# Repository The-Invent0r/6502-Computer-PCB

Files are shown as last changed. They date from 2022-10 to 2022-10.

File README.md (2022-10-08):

# 6502-Computer-PCB

DISCLAIMER: I DELETED ALL OF THE CONNECTIONS FOR GRANT SEARLE'S VIDEO+KEYBOARD INTERFACE BEFORE UPLOADING THE FILES. IF YOU WANT TO ADD IN THE VIDEO+KEYBOARD INTERFACE PLEASE TAKE A LOOK AT HIS WEBSITE (http://searle.x10host.com/MonitorKeyboard/index.html) AND FOLLOW THE DIRECTIONS ON THERE. IT MIGHT BE WORTH IT TO PROTOTYPE THE INTERFACE ON BREADBOARDS FIRST.

I made this Modified version of Ben Eater's 6502 computer PCB and decided instead of adding a VGA video card, I wanted to connect this to a CRT monitor using a composite video cable. 
I decided to add in a 6551 ACIA (Asyncronous Communications Interface Adapter) to give the computer serial I/O capabilites. I then found Grant Searle's video+keyboard interface and decided to incorporate that into my design. 
The only issue was that my 6551 was sending and receiving data at 19200 baud, and the video+keyboard interface was running at 115200 baud. Luckily it was an easy fix to go into the software and update the USART_BAUD variable from 115200u1 to 19200u1. 
However, before uploading the code I changed the fuse bytes to ensure that the 2 AVR chips were running at the correct crystal oscillator frequencies. 
To upload the code for the keyboard chip I used WinAVR. I found that before uploading the keyboard interface code, I needed to change the file name to main.c and I also had to create my own makefile for the atmega328p. 
For the video chip I decided to use the .hex file, and burn that directly into the other atmega328p using the command line. 
When I first prototyped this circuit on breadboards I had a lot of issues which I later discovered were caused by using a low quality breadboard. So if all off your connections and software are correct, try using a more expensive but higher quality BB830 breadboard.
When you first connect the circuit to an LCD monitor or CRT monitor you should see a cursor blinking. In order to conduct a loopback test of the circuit, simply connect the Rx pin to the Tx pin on the keyboard chip, then connect the PS2 keyboard and start typing. If it works then you'll see the correct characters on the screen.

I also made a YouTube video briefly documenting my progress and demonstrating the workings of the computer. (https://youtu.be/8I7XNCFC5iU)




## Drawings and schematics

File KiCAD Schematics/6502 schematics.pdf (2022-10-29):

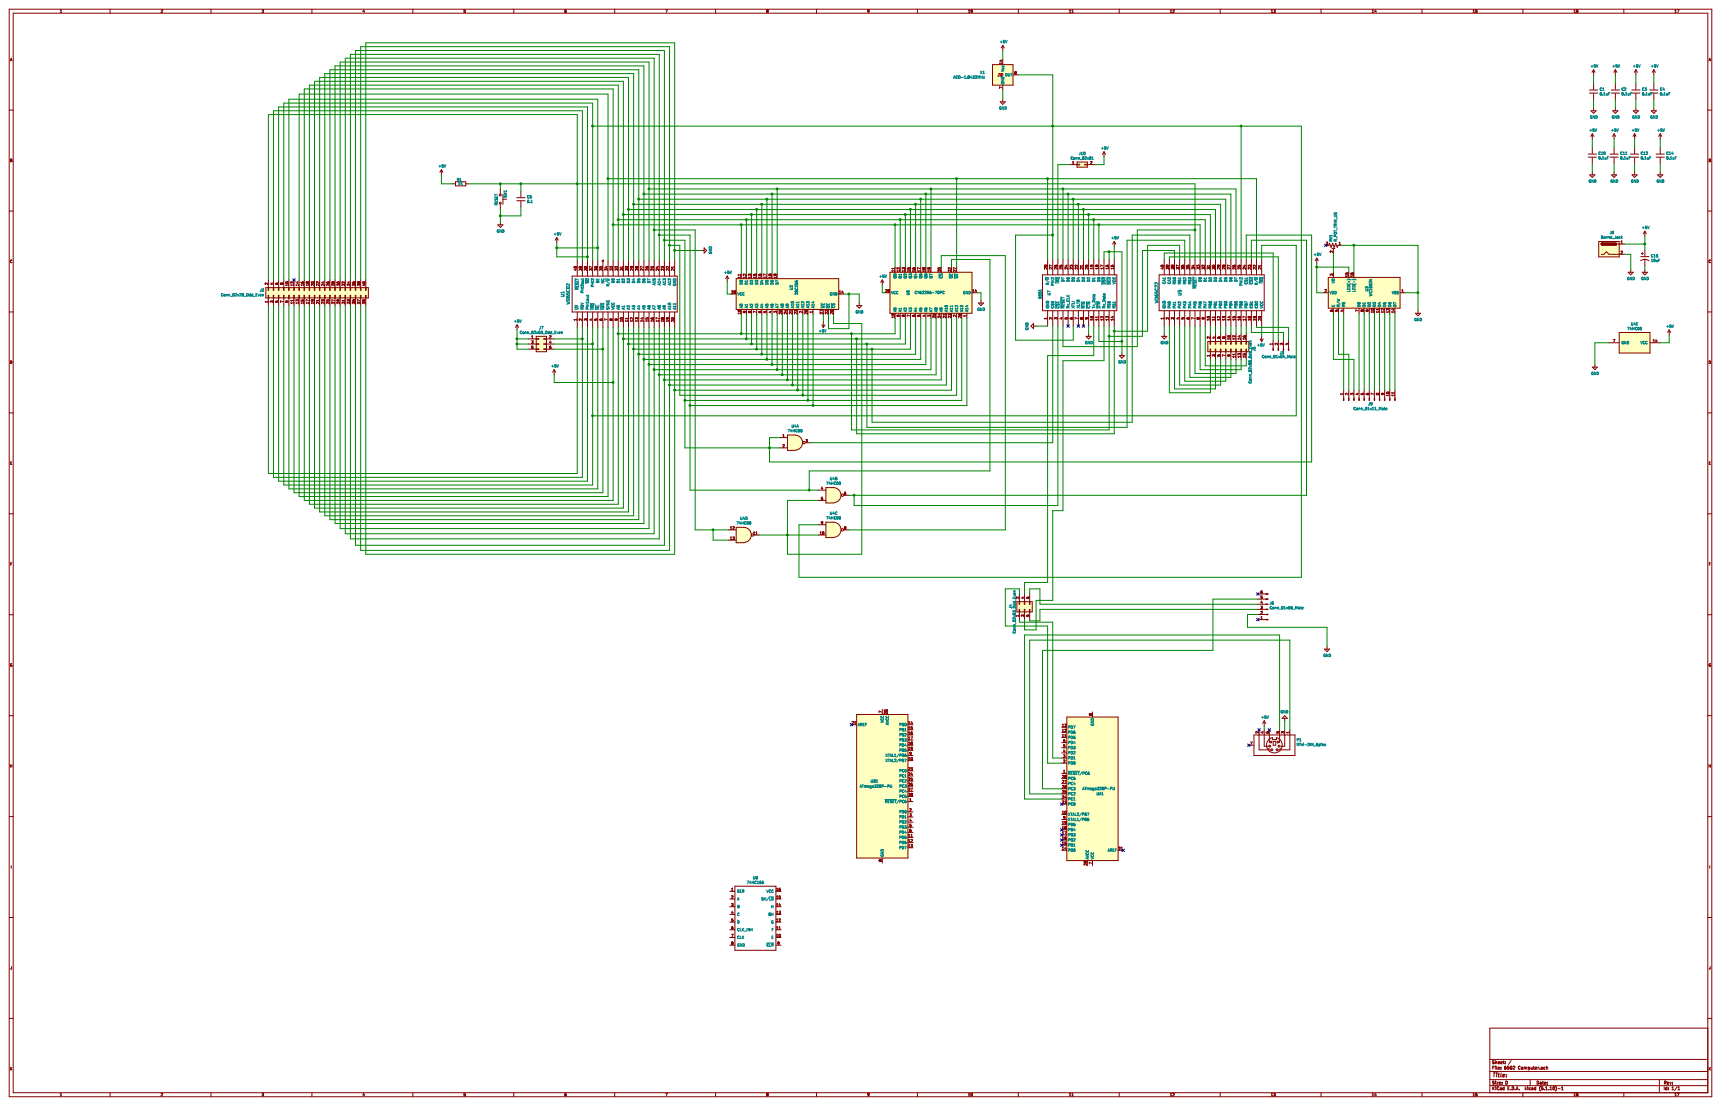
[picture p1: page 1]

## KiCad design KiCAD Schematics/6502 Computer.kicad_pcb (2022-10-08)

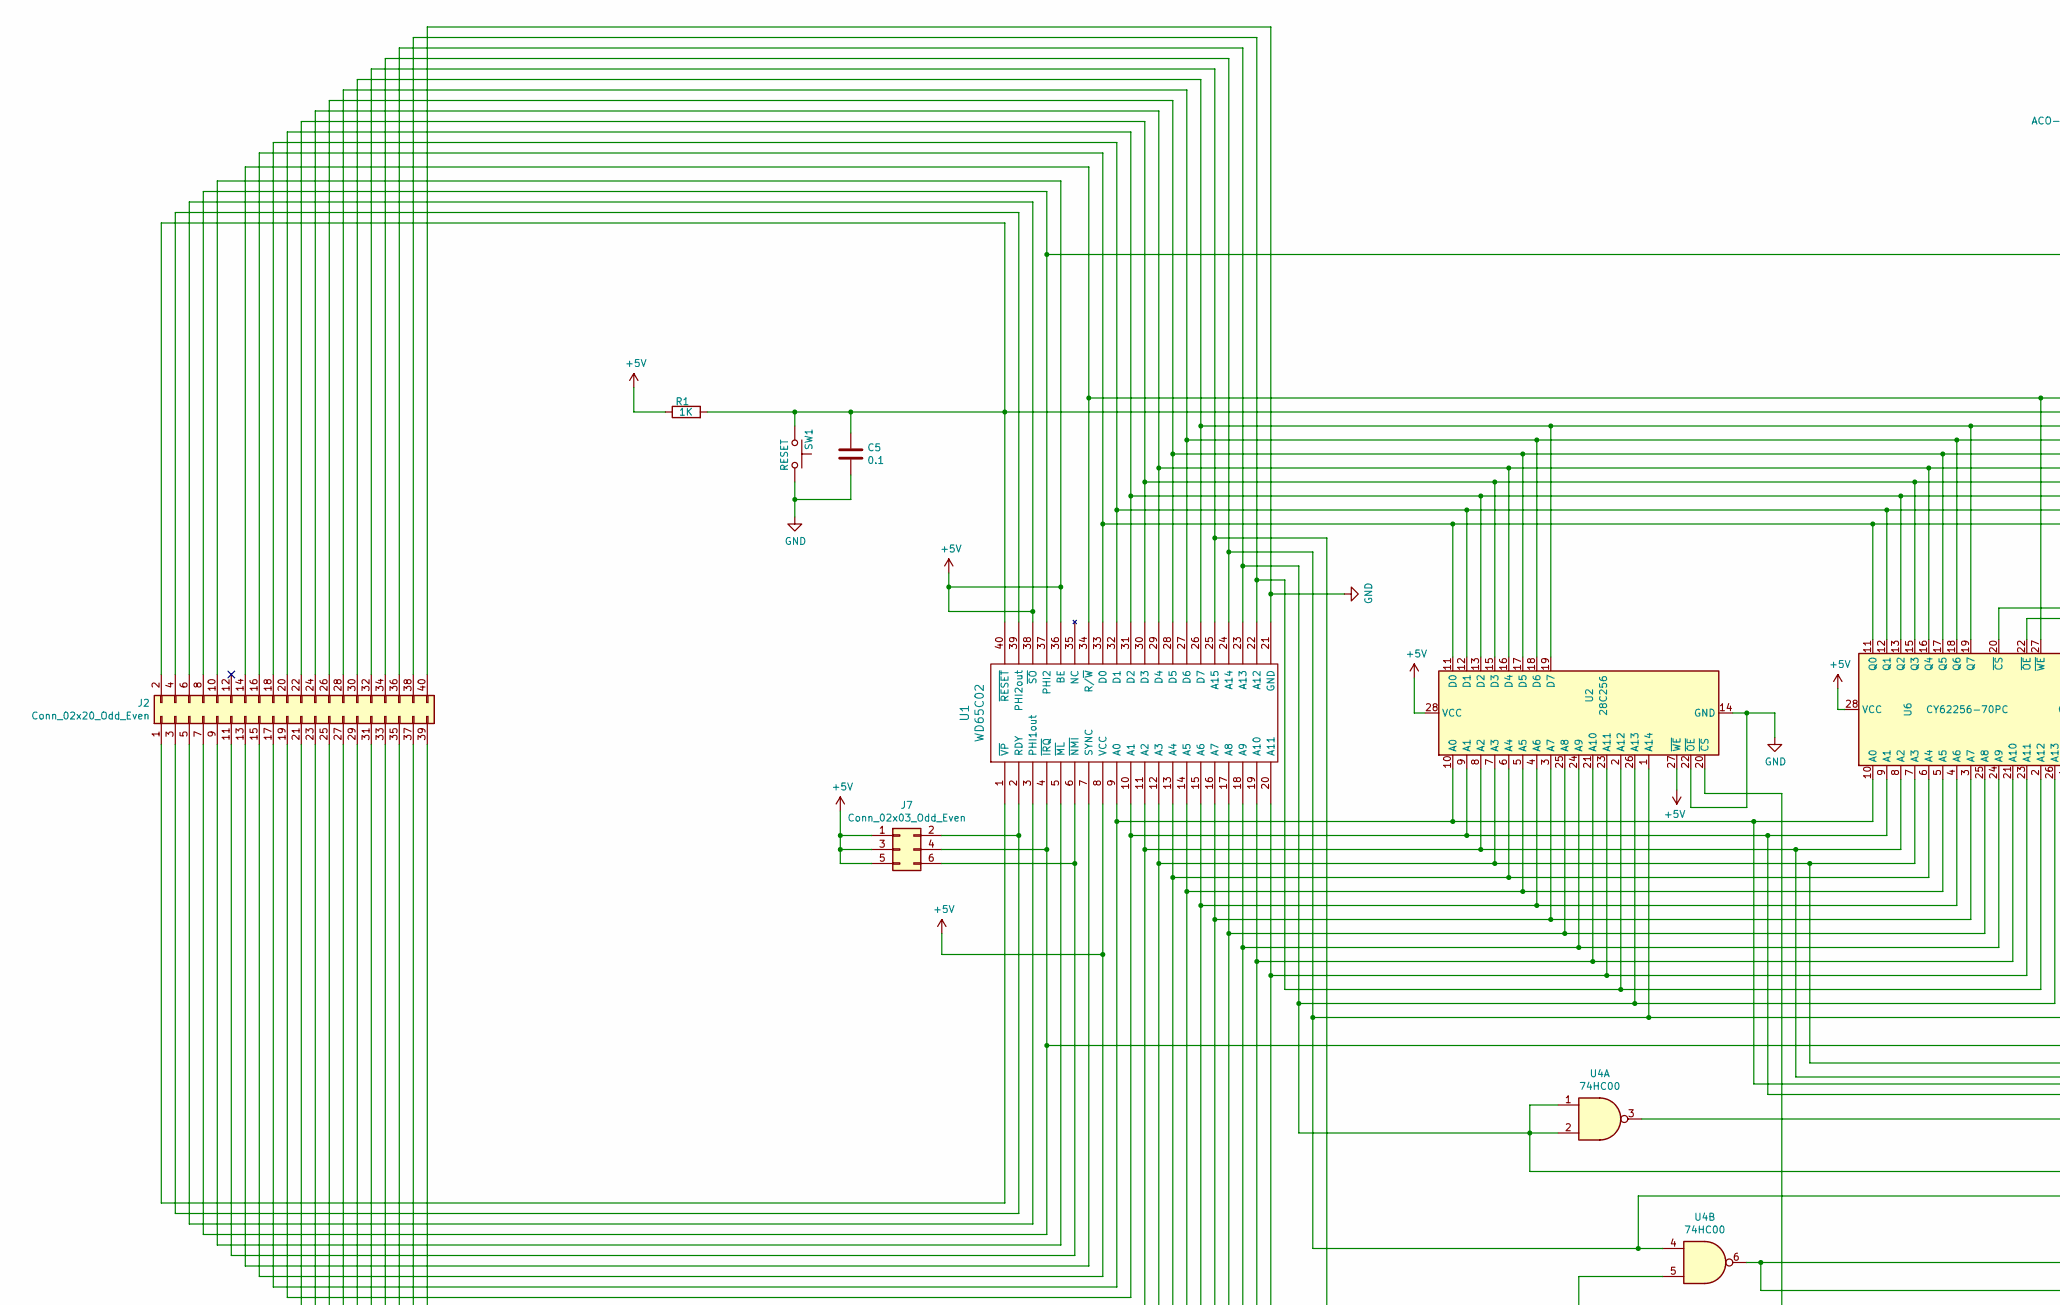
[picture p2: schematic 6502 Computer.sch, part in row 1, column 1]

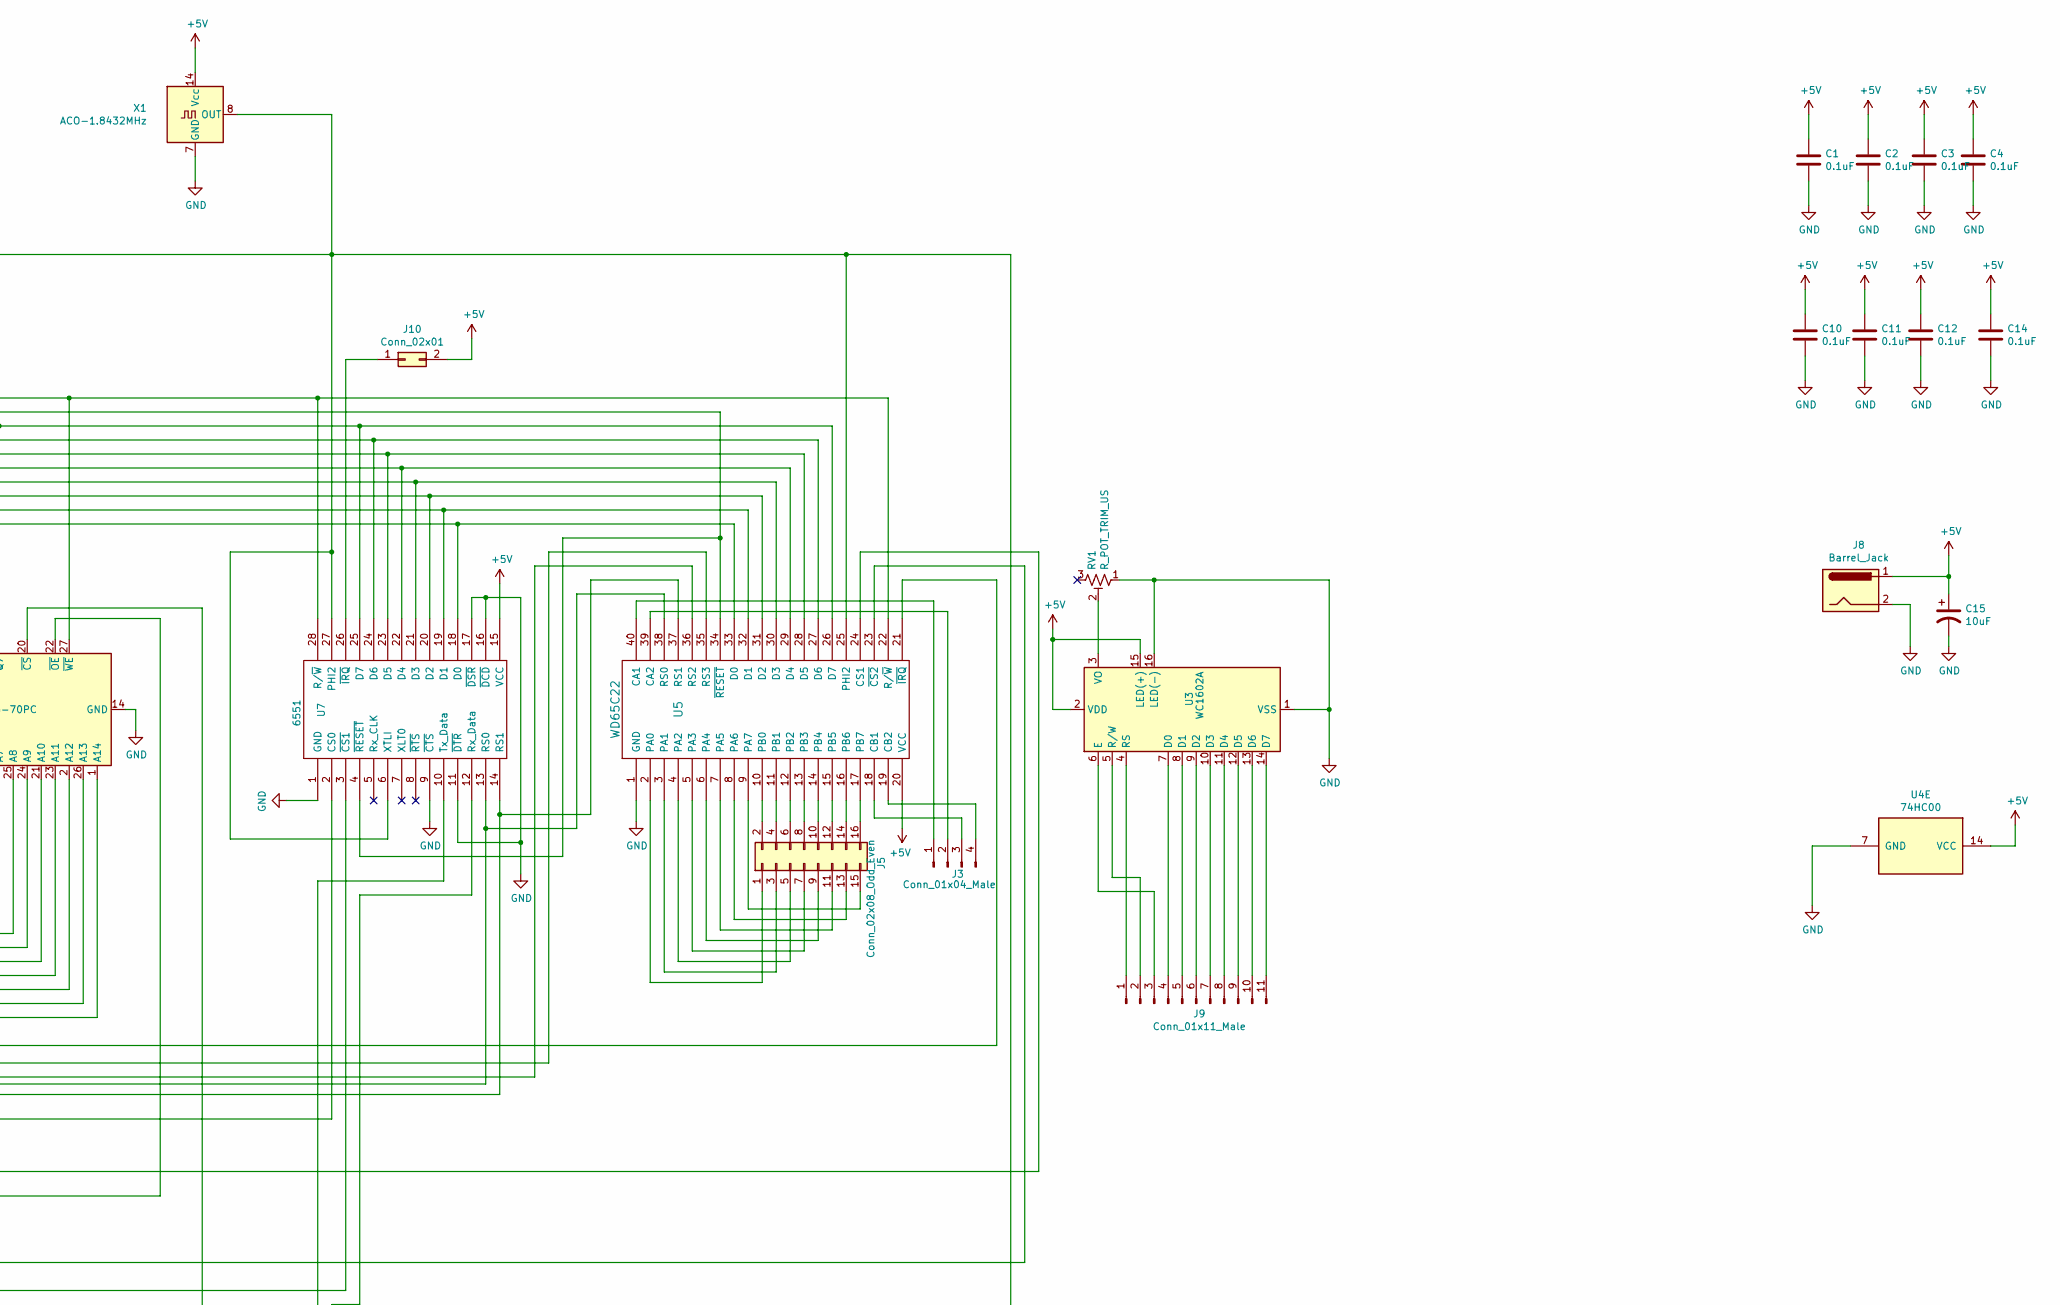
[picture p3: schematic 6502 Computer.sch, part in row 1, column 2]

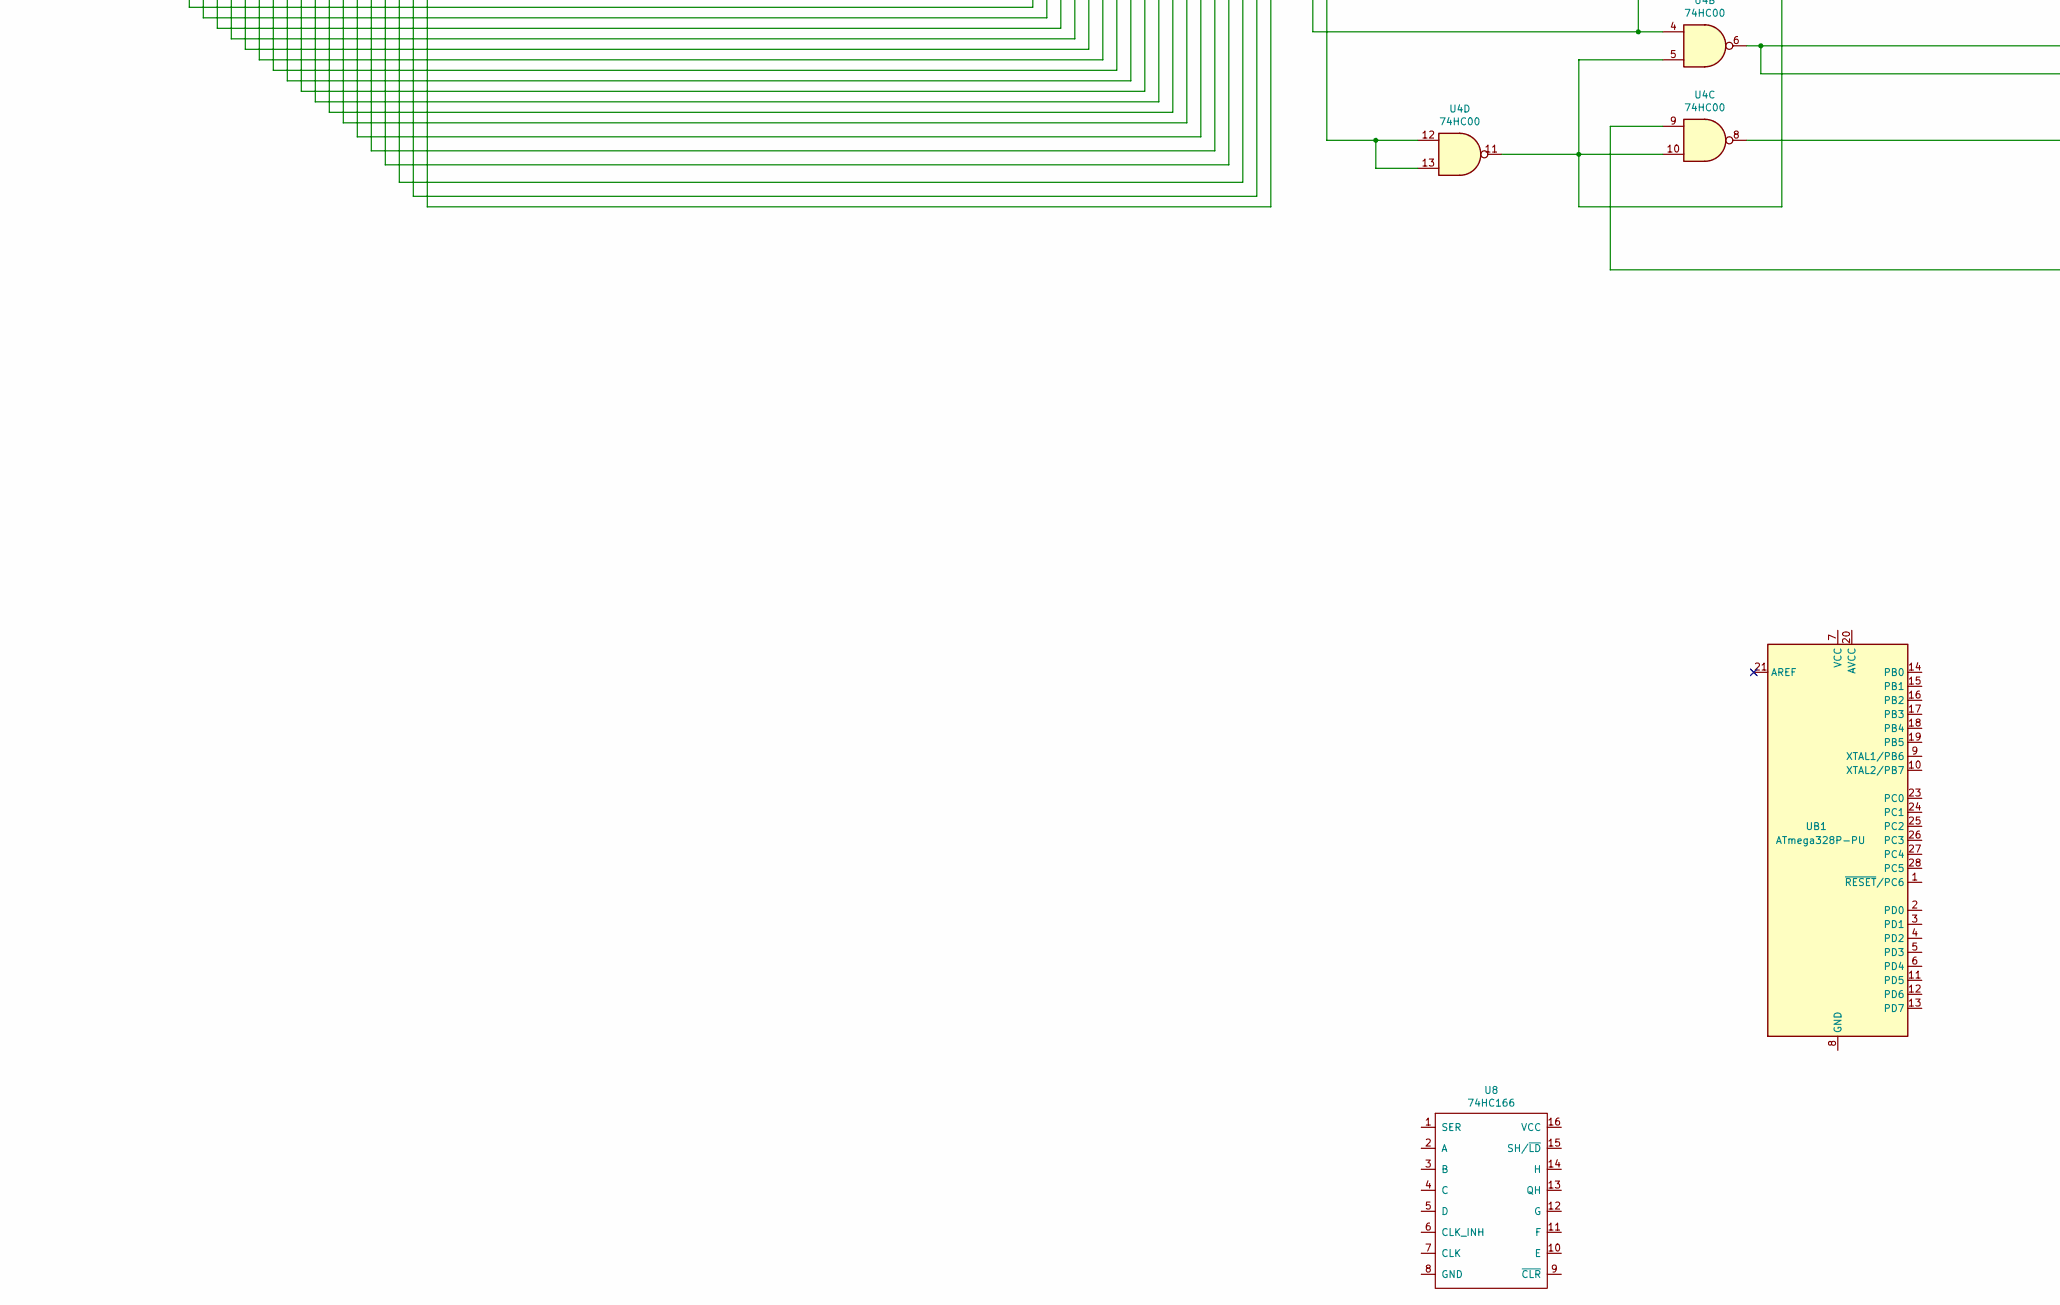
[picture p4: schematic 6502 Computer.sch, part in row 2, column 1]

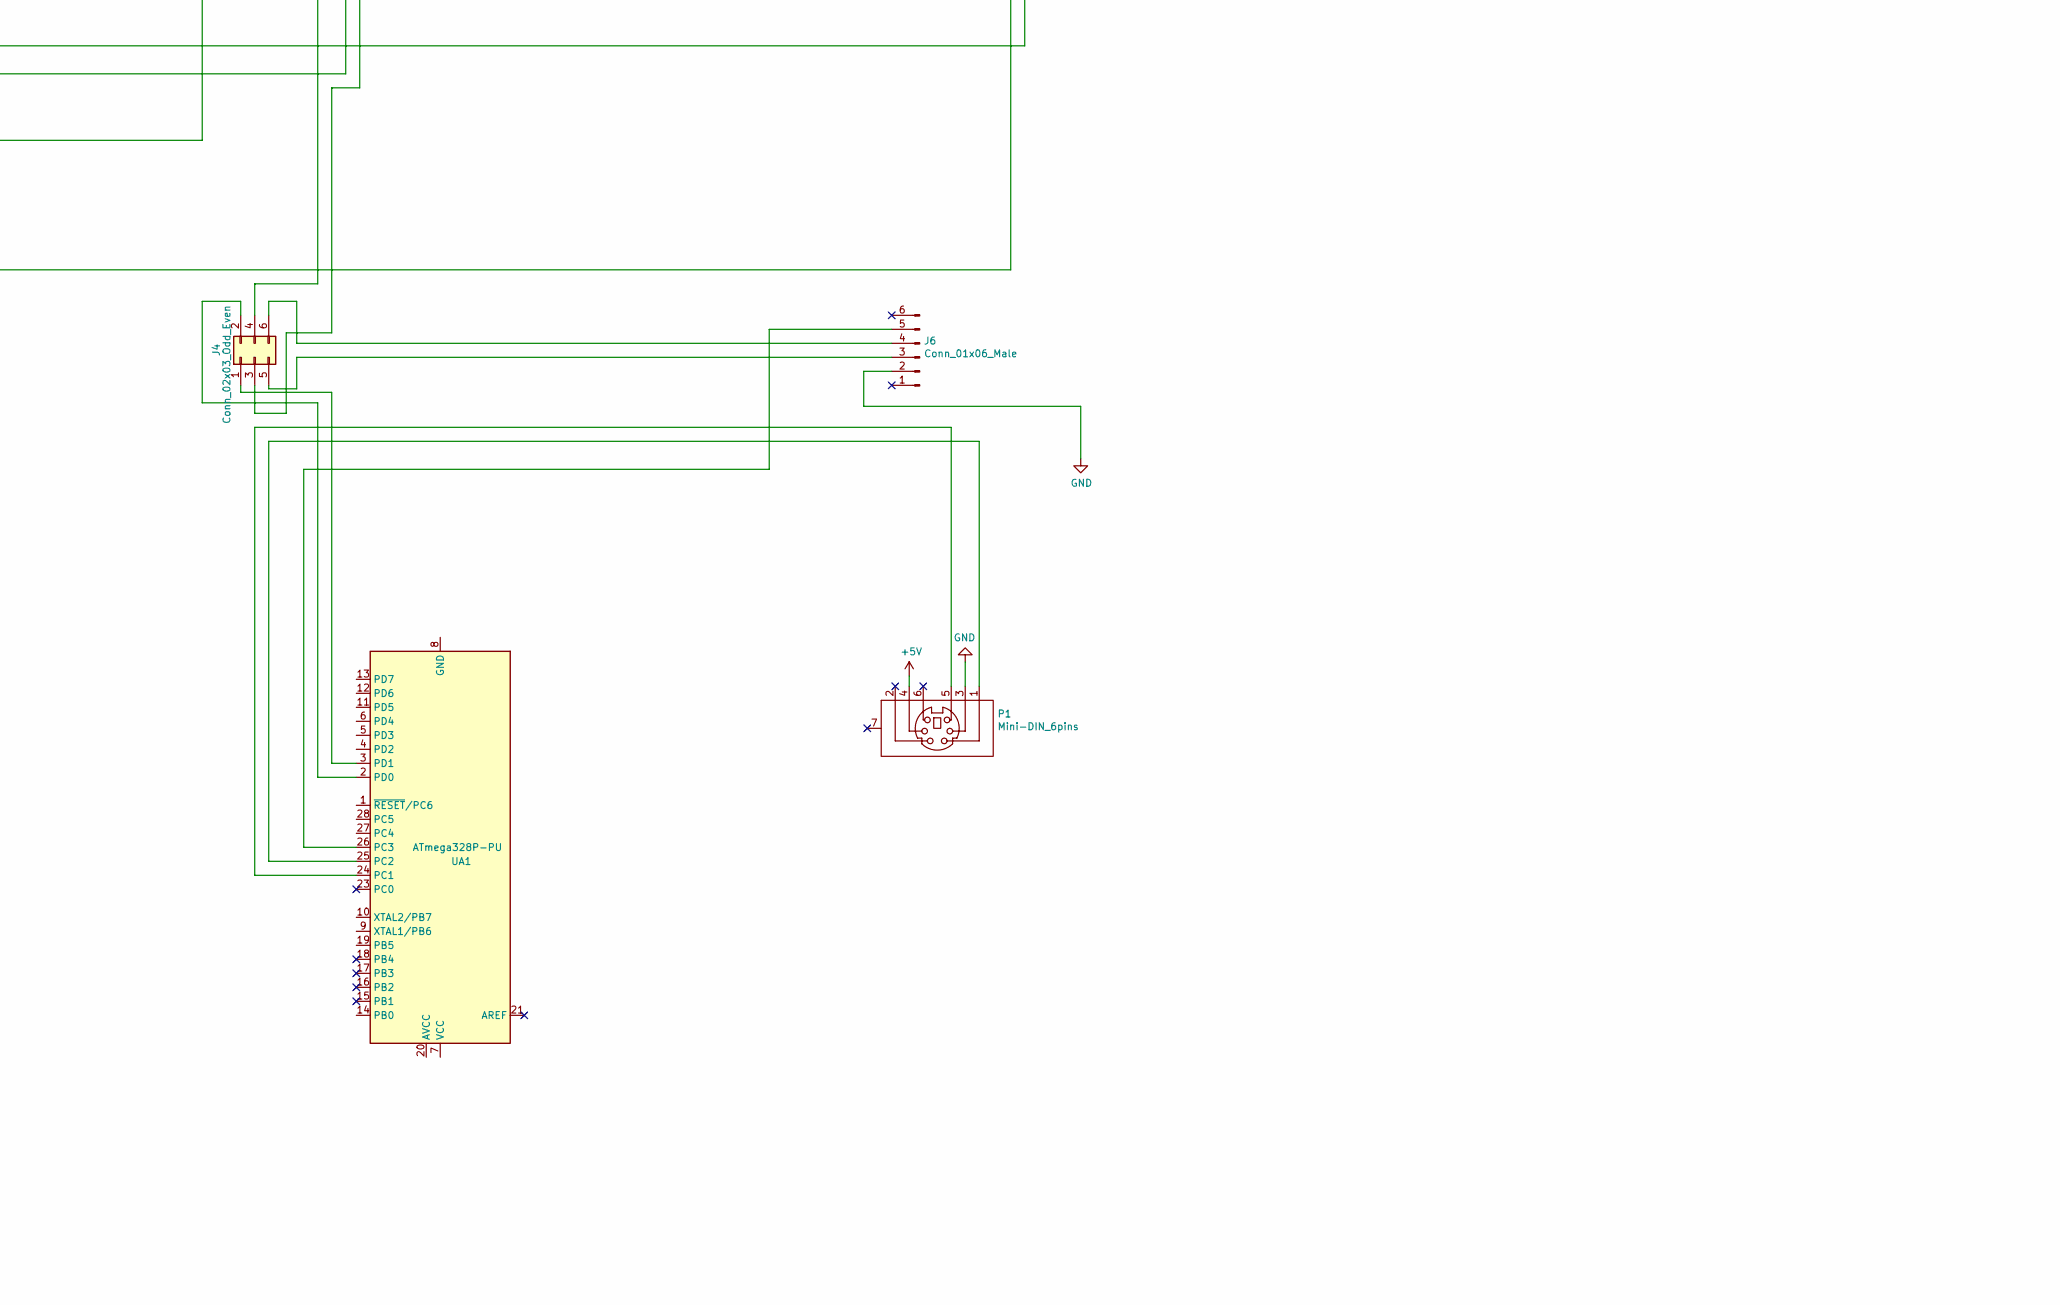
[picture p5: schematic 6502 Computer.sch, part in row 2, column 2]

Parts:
C1, C2, C3, C4, C10, C11, C12, C14: 0.1uF; C_Disc_D4.3mm_W1.9mm_P5.00mm
C5: 0.1; C_Disc_D4.3mm_W1.9mm_P5.00mm
C15: 10uF; CP_Radial_D5.0mm_P2.00mm
J2: Conn_02x20_Odd_Even; PinHeader_2x20_P2.54mm_Vertical
J3: Conn_01x04_Male; PinHeader_1x04_P2.54mm_Vertical
J4, J7: Conn_02x03_Odd_Even; PinHeader_2x03_P2.54mm_Vertical
J5: Conn_02x08_Odd_Even; PinHeader_2x08_P2.54mm_Vertical
J6: Conn_01x06_Male; PinHeader_1x06_P2.54mm_Horizontal
J8: Barrel_Jack; BarrelJack_CUI_PJ-063AH_Horizontal
J9: Conn_01x11_Male; PinHeader_1x11_P2.54mm_Vertical
J10: Conn_02x01; PinHeader_2x01_P2.54mm_Vertical
P1: Mini-DIN_6pins; Connector_Mini-DIN_Female_6Pin_2rows
R1: 1K; R_Axial_DIN0207_L6.3mm_D2.5mm_P7.62mm_Horizontal
RV1: R_POT_TRIM_US; Potentiometer_Bourns_3386C_Horizontal
SW1: RESET; SW_PUSH_6mm_H5mm
U1: WD65C02; DIP-40_W15.24mm_Socket_LongPads
U2: 28C256; DIP-28_W15.24mm_Socket_LongPads
U3: WC1602A
U4: 74HC00; DIP-14_W7.62mm_Socket_LongPads
U5: WD65C22; DIP-40_W15.24mm_Socket_LongPads
U6: CY62256-70PC; DIP-28_W15.24mm_Socket_LongPads
U7: 6551; DIP-28_W15.24mm_Socket_LongPads
U8: 74HC166; DIP-16_W7.62mm_Socket_LongPads
UA1: ATmega328P-PU; DIP-28_W7.62mm_Socket_LongPads
UB1: ATmega328P-PU; DIP-28_W7.62mm_Socket_LongPads
X1: ACO-1.8432MHz; Oscillator_DIP-14

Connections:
+5V: C1.1, C2.1, C3.1, C4.1, C10.1, C11.1, C12.1, C14.1, C15.1, J2.6, J2.10, J2.15, J7.1, J7.3, J7.5, J8.1, J10.2, P1.4, R1.1, U1.8 (VCC), U1.36 (BE), U1.38 (~SO), U2.27 (~WE), U2.28 (VCC), U3.2 (VDD), U3.15 (LED(+)), U4.14 (VCC), U5.20 (VCC), U6.28 (VCC), U7.15 (VCC), X1.14 (Vcc)
GND: C1.2, C2.2, C3.2, C4.2, C5.2, C10.2, C11.2, C12.2, C14.2, C15.2, J2.40, J6.2, J8.2, P1.3, RV1.1, SW1.2, U1.21 (GND), U2.14 (GND), U2.22 (~OE), U3.1 (VSS), U3.16 (LED(-)), U4.7 (GND), U5.1 (GND), U6.14 (GND), U7.1 (GND), U7.9 (~CTS), U7.11 (~DTR), U7.16 (~DCD), U7.17 (~DSR), X1.7 (GND)
unnamed: C5.1, J2.2, R1.2, SW1.1, U1.40 (~RESET), U5.34 (~RESET), U7.4 (~RESET)
unnamed: J2.1, U1.1 (~VP)
unnamed: J2.3, J7.2, U1.2 (RDY)
unnamed: J2.4, U1.39 (PHI2out)
unnamed: J2.5, U1.3 (PHI1out)
unnamed: J2.7, J7.4, U1.4 (~IRQ), U5.21 (~IRQ)
unnamed: J2.8, U1.37 (PHI2), U4.9, U5.25 (PHI2), U7.6 (XTLI), U7.27 (PHI2), X1.8 (OUT)
unnamed: J2.9, U1.5 (~ML)
unnamed: J2.11, J7.6, U1.6 (~NMI)
unnamed: J2.13, U1.7 (SYNC)
unnamed: J2.14, U1.34 (R/~W), U5.22 (R/~W), U6.27 (~WE), U7.28 (R/~W)
unnamed: J2.16, U1.33 (D0), U2.11 (D0), U5.33 (D0), U6.11 (Q0), U7.18 (D0)
unnamed: J2.17, U1.9 (A0), U2.10 (A0), U5.38 (RS0), U6.10 (A0), U7.13 (RS0)
unnamed: J2.18, U1.32 (D1), U2.12 (D1), U5.32 (D1), U6.12 (Q1), U7.19 (D1)
unnamed: J2.19, U1.10 (A1), U2.9 (A1), U5.37 (RS1), U6.9 (A1), U7.14 (RS1)
unnamed: J2.20, U1.31 (D2), U2.13 (D2), U5.31 (D2), U6.13 (Q2), U7.20 (D2)
unnamed: J2.21, U1.11 (A2), U2.8 (A2), U5.36 (RS2), U6.8 (A2)
unnamed: J2.22, U1.30 (D3), U2.15 (D3), U5.30 (D3), U6.15 (Q3), U7.21 (D3)
unnamed: J2.23, U1.12 (A3), U2.7 (A3), U5.35 (RS3), U6.7 (A3)
unnamed: J2.24, U1.29 (D4), U2.16 (D4), U5.29 (D4), U6.16 (Q4), U7.22 (D4)
unnamed: J2.25, U1.13 (A4), U2.6 (A4), U6.6 (A4)
unnamed: J2.26, U1.28 (D5), U2.17 (D5), U5.28 (D5), U6.17 (Q5), U7.23 (D5)
unnamed: J2.27, U1.14 (A5), U2.5 (A5), U6.5 (A5)
unnamed: J2.28, U1.27 (D6), U2.18 (D6), U5.27 (D6), U6.18 (Q6), U7.24 (D6)
unnamed: J2.29, U1.15 (A6), U2.4 (A6), U6.4 (A6)
unnamed: J2.30, U1.26 (D7), U2.19 (D7), U5.26 (D7), U6.19 (Q7), U7.25 (D7)
unnamed: J2.31, U1.16 (A7), U2.3 (A7), U6.3 (A7)
unnamed: J2.32, U1.25 (A15), U4.12, U4.13
unnamed: J2.33, U1.17 (A8), U2.25 (A8), U6.25 (A8)
unnamed: J2.34, U1.24 (A14), U2.1 (A14), U4.4, U6.1 (A14), U6.22 (~OE)
unnamed: J2.35, U1.18 (A9), U2.24 (A9), U6.24 (A9)
unnamed: J2.36, U1.23 (A13), U2.26 (A13), U4.1, U4.2, U5.24 (CS1), U6.26 (A13)
unnamed: J2.37, U1.19 (A10), U2.21 (A10), U6.21 (A10)
unnamed: J2.38, U1.22 (A12), U2.2 (A12), U6.2 (A12)
unnamed: J2.39, U1.20 (A11), U2.23 (A11), U6.23 (A11)
unnamed: J3.1, U5.40 (CA1)
unnamed: J3.2, U5.39 (CA2)
unnamed: J3.3, U5.18 (CB1)
unnamed: J3.4, U5.19 (CB2)
unnamed: J4.1, UA1.3 (PD1)
unnamed: J4.2, UA1.2 (PD0)
unnamed: J4.3, U7.12 (Rx_Data)
unnamed: J4.4, U7.10 (Tx_Data)
unnamed: J4.5, J6.3
unnamed: J4.6, J6.4
unnamed: J5.1, U5.2 (PA0)
unnamed: J5.2, U5.10 (PB0)
unnamed: J5.3, U5.3 (PA1)
unnamed: J5.4, U5.11 (PB1)
unnamed: J5.5, U5.4 (PA2)
unnamed: J5.6, U5.12 (PB2)
unnamed: J5.7, U5.5 (PA3)
unnamed: J5.8, U5.13 (PB3)
unnamed: J5.9, U5.6 (PA4)
unnamed: J5.10, U5.14 (PB4)
unnamed: J5.11, U5.7 (PA5)
unnamed: J5.12, U5.15 (PB5)
unnamed: J5.13, U5.8 (PA6)
unnamed: J5.14, U5.16 (PB6)
unnamed: J5.15, U5.9 (PA7)
unnamed: J5.16, U5.17 (PB7)
unnamed: J6.5, UA1.26 (PC3)
unnamed: J9.1, U3.4 (RS)
unnamed: J9.2, U3.5 (R/W)
unnamed: J9.3, U3.6 (E)
unnamed: J9.4, U3.7 (D0)
unnamed: J9.5, U3.8 (D1)
unnamed: J9.6, U3.9 (D2)
unnamed: J9.7, U3.10 (D3)
unnamed: J9.8, U3.11 (D4)
unnamed: J9.9, U3.12 (D5)
unnamed: J9.10, U3.13 (D6)
unnamed: J9.11, U3.14 (D7)
unnamed: J10.1, U7.26 (~IRQ)
unnamed: P1.1, UA1.25 (PC2)
unnamed: P1.5, UA1.24 (PC1)
unnamed: RV1.2, U3.3 (VO)
unnamed: U2.20 (~CS), U4.5, U4.10, U4.11
unnamed: U4.3, U7.2 (CS0)
unnamed: U4.6, U5.23 (~CS2), U7.3 (~CS1)
unnamed: U4.8, U6.20 (~CS)
unnamed: UA1.8 (GND), UA1.22 (GND)
unnamed: UB1.8 (GND), UB1.22 (GND)

Board: 2 copper layers, 34 parts (0 on the bottom side), 85 nets, no tracks yet.

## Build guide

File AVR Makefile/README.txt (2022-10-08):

All the rest of the software used for the AVR chips can be found at Grant Searle's website (http://searle.x10host.com/MonitorKeyboard/index.html)

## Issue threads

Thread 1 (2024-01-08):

PCB file

nidhi123457890, 2024-01-08:
It might be a question of dumbness.

I am unable to find the **final Gerber file** which i can print the get the same output as in your video.

Please tell the browsing address of the Gerber file.

I will be highly grateful to you if you help me in this work.

Closed 2025-09-29.
